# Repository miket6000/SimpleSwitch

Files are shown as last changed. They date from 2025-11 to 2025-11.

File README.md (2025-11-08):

# SimpleSwitch

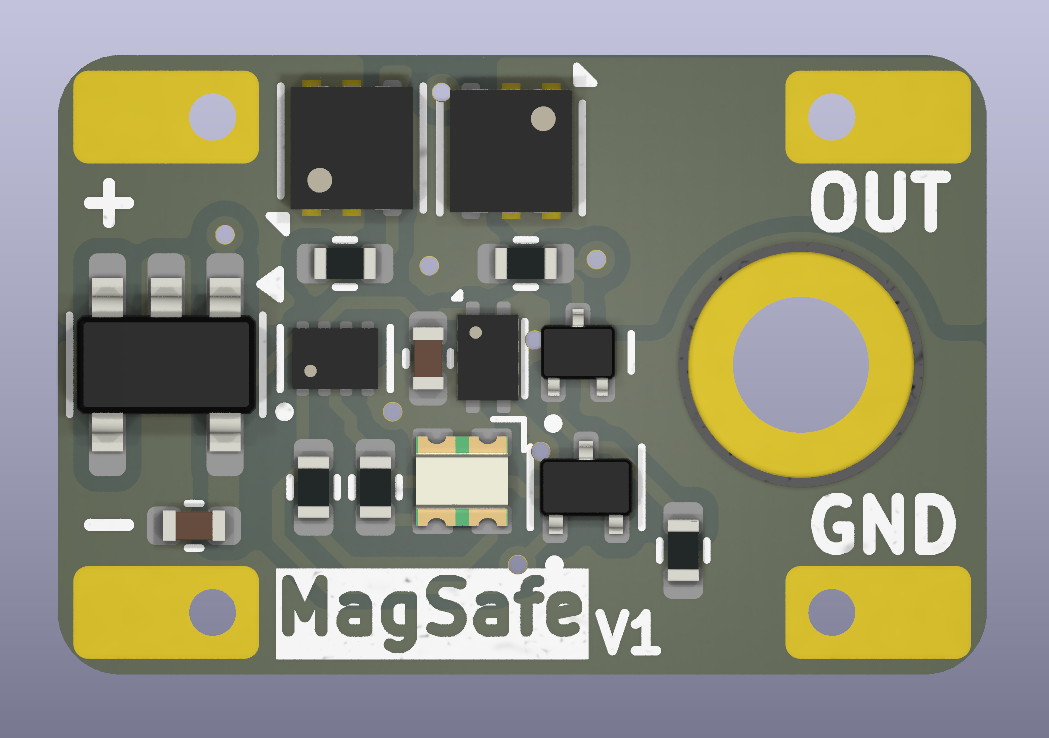
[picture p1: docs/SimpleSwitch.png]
Render of SimpleSwitch


SimpleSwitch is a magneticly operated electronic switch designed for model rocketry. It is a 15x10mm PCB with an input and output capable of switching approximately 4A continuous and 10A for 10s. It can accept an input voltage of up to 12V and also includes reverse polarity protection to prevent damage to the switch or downstream electronics in the event that the battery is accidentally connected backwards.

It is designed specifically to be easy to turn on, but to require multiple steps to turn off. This is to prevent issues with accidental turn off which can occur with traditional magnetic switches when they pass by magnatized hardware on launch towers/rails.

The magnetic switch draws a very small amount of power from the battery when plugged in. This is calculated at 3uA worst case, so a small 150mAh 1s battery should last approximately 5 years. On larger batteries this is quickly swamped by the batteries self discharge rate.

## Operation

Use of the SimpleSwitch is easy. Bringing a magnetic south pole near the top of the board will result in the switch turning on and illuminating both the red and green LEDs, the switch is now in the "ON" state. 

To turn off the switch you nead to put a North pole near the switch which will cause the red LED to turn off ("OK" state). Bringing a South pole near the switch will then cause the green LED to turn off and the red LED to turn back on ("WARNING" State). One more north pole will cause the red LED to turn off and the switch to disable the output ("OFF" State).

In summary as you alernate South-\>North-\>South-\>North you step through the states as shown below:

| Magnetic Pole | State Name  | Red LED | Green LED | Switch State |
|---|---|---|---|---|
| | OFF | OFF | OFF | OFF |
| SOUTH | ON | ON | ON | ON |
| NORTH | OK | OFF | ON | ON |
| SOUTH | WARNING | ON | OFF | ON |
| NORTH | OFF | OFF | OFF | OFF |

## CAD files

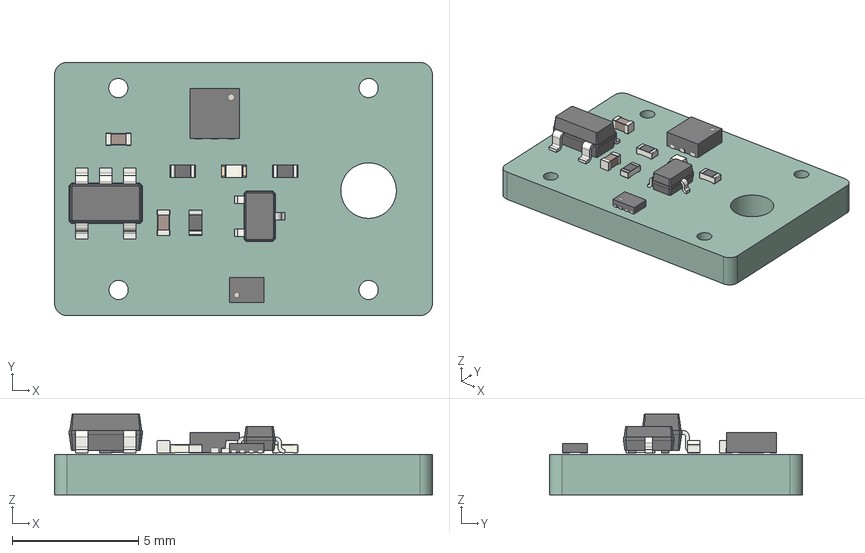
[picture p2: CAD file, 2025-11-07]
hardware/magnetic_switch.step
15.0 x 10.0 x 3.20 mm
R_0402_1005Metric x 3
WSON_6_1EP_2x2mm_P065mm_EP1x16mm
C_0402_1005Metric x 2
SOT_323_SC_70
X2SON_8_14x1mm_Pitch035mm
LED_0402_1005Metric
SOT_23_5
magnetic_switch_PCB

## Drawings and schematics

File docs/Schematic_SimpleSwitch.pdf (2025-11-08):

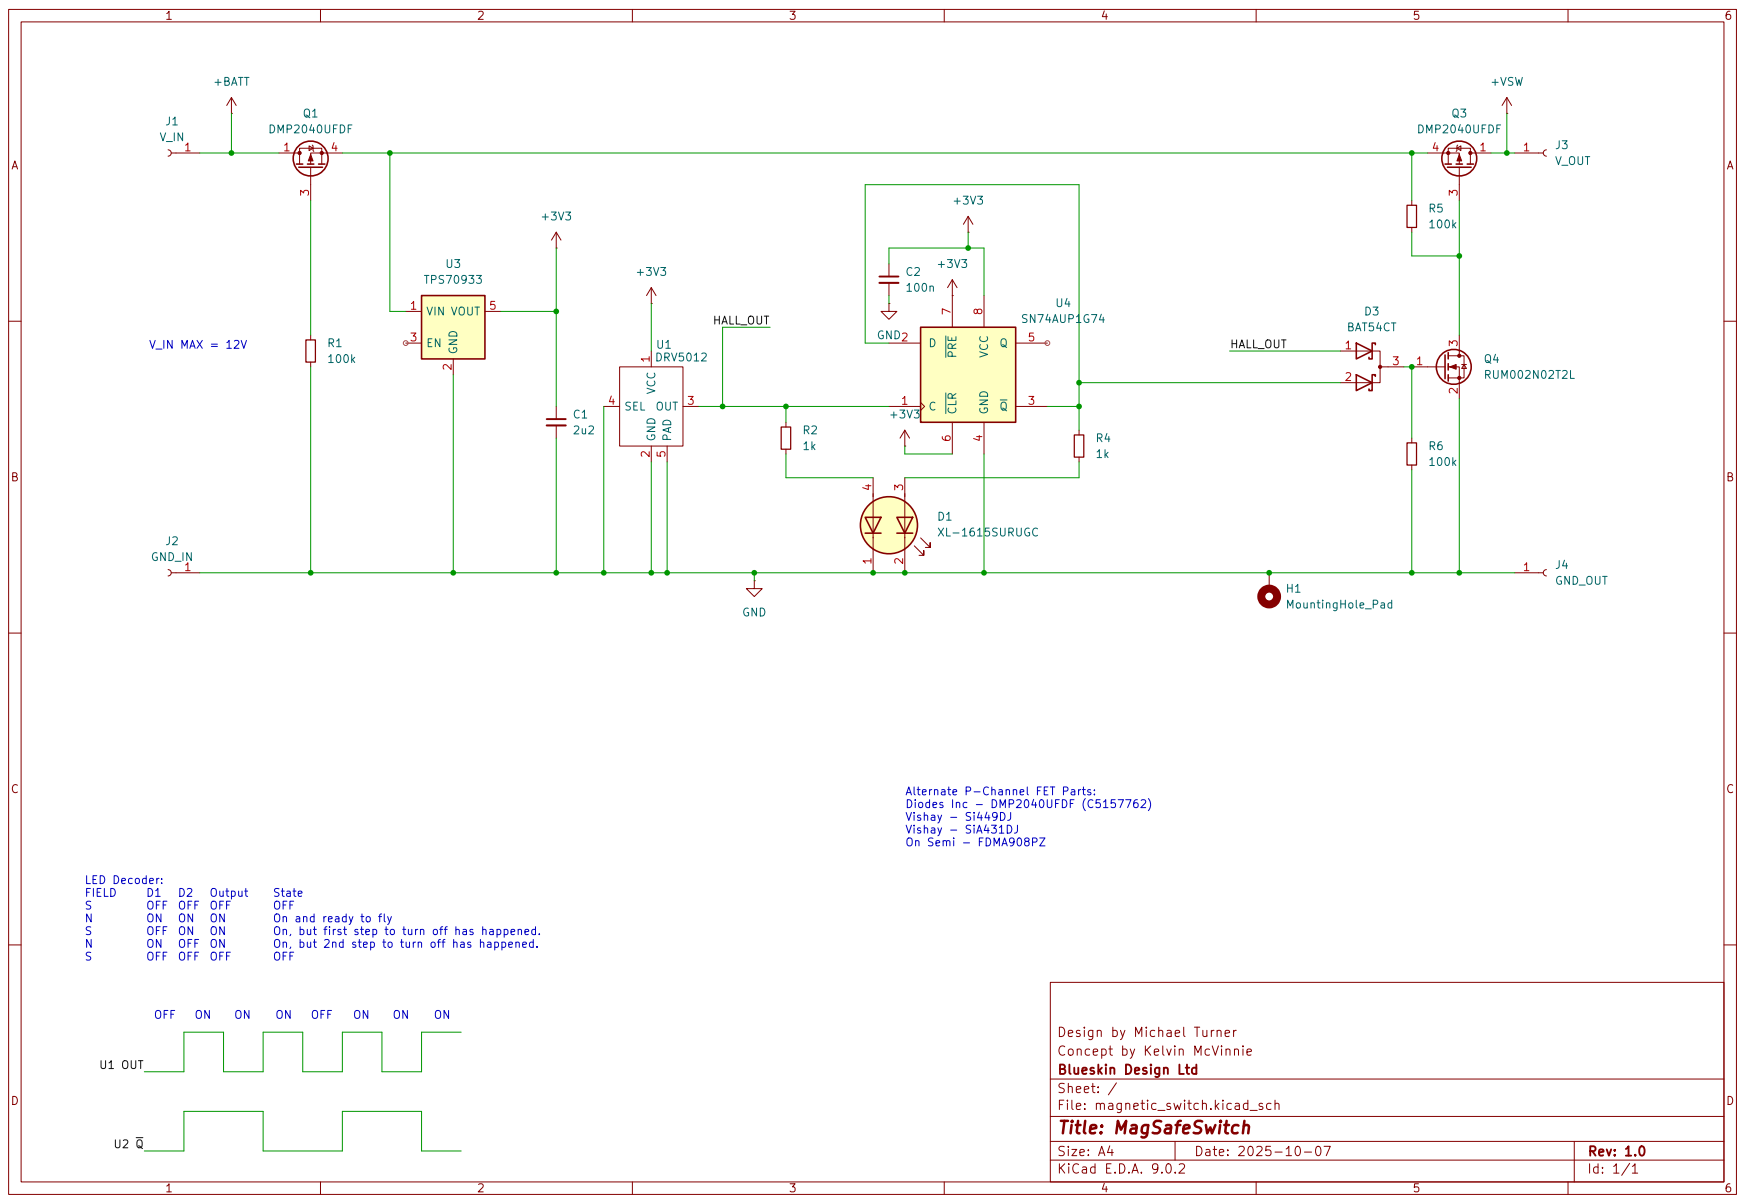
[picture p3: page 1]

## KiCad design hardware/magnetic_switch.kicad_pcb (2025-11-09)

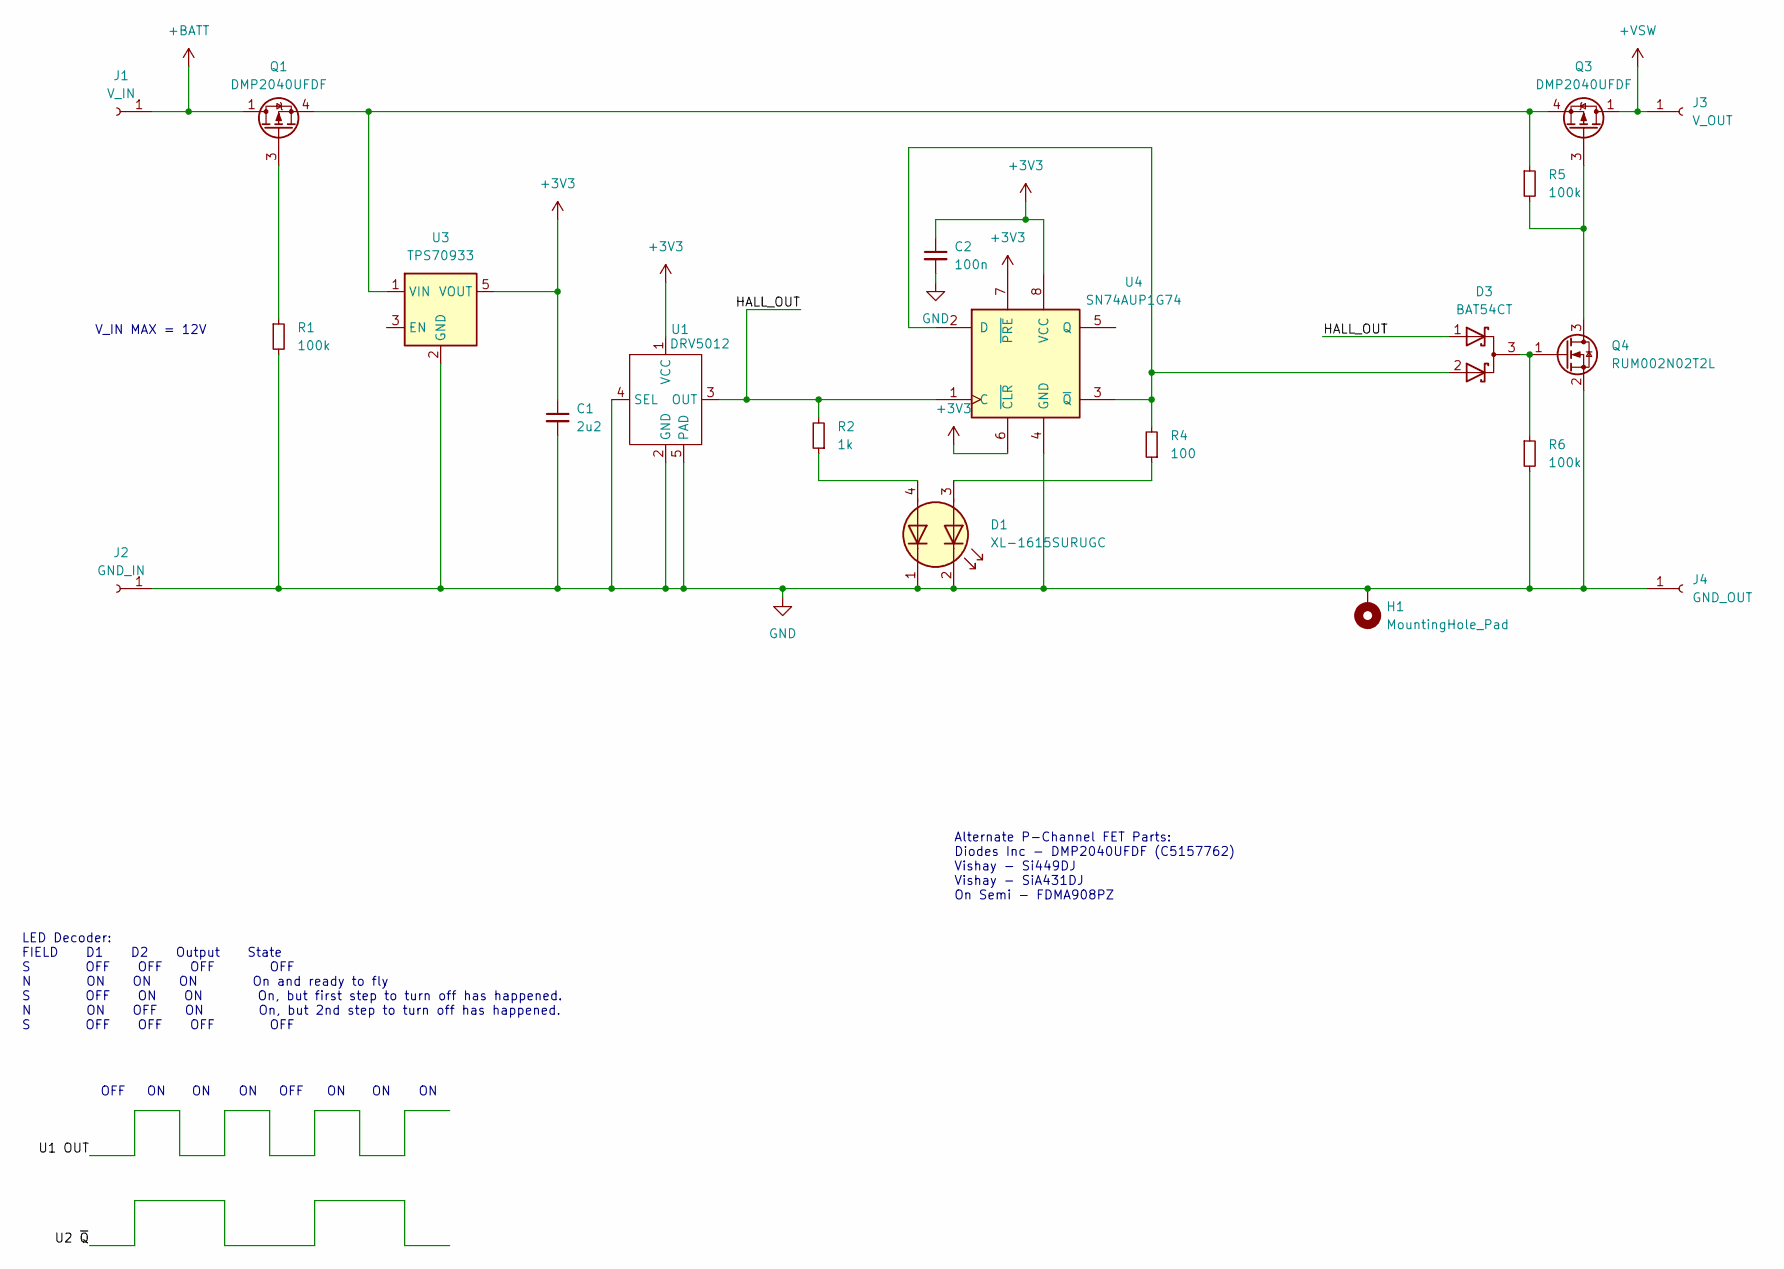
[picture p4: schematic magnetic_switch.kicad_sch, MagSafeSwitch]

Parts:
C1: 2u2; C_0402_1005Metric
C2: 100n; C_0402_1005Metric
D1: XL-1615SURUGC; LED_SMT_DUAL_1615; JLCPCB Part # C965839
D3: BAT54CT; SOT-523; JLCPCB Part # C134407
H1: MountingHole_Pad; MountingHole_2.2mm_M2_DIN965_Pad
J1: V_IN; WireSolderPad_w_hole
J2: GND_IN; WireSolderPad_w_hole
J3: V_OUT; WireSolderPad_w_hole
J4: GND_OUT; WireSolderPad_w_hole
Q1, Q3: DMP2040UFDF; Vishay_PowerPAK_SC70-6L_Single; JLCPCB Part # C5157762
Q4: RUM002N02T2L; SOT-723; JLCPCB Part # C250130
R1, R5, R6: 100k; R_0402_1005Metric
R2: 1k; R_0402_1005Metric
R4: 100; R_0402_1005Metric
U1: DRV5012; X2SON_4_EP; JLCPCB Part # C2655038
U3: TPS70933; SOT-23-5; JLCPCB Part # C89347
U4: SN74AUP1G74; X2SON-8_1.4x1mm_P0.35mm; JLCPCB Part # C2677745

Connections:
+3V3: C1.1, C2.1, U1.1 (VCC), U3.5 (VOUT), U4.6 (~CLR), U4.7 (~PRE), U4.8 (VCC)
+BATT: J1.1, Q1.1 (D)
+VSW: J3.1, Q3.1 (D)
/HALL_OUT: D3.1 (A), R2.2, U1.3 (OUT), U4.1 (C)
GND: C1.2, C2.2, D1.1 (K2), D1.2 (K1), H1.1, J2.1, J4.1, Q4.2 (S), R1.2, R6.2, U1.2 (GND), U1.4 (SEL), U1.5 (PAD), U3.2 (GND), U4.4 (GND)
unnamed: D1.3 (A1), R4.1
unnamed: D1.4 (A2), R2.1
unnamed: D3.3 (K), Q4.1 (G), R6.1
unnamed: Q1.3 (G), R1.1
unnamed: Q1.4 (S), Q3.4 (S), R5.1, U3.1 (VIN)
unnamed: Q3.3 (G), Q4.3 (D), R5.2
unnamed: D3.2 (A), R4.2, U4.2 (D), U4.3 (~Q)

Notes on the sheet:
OFF
LED Decoder: FIELD D1 D2 Output State S OFF OFF OFF OFF N ON ON ON On and ready to fly S OFF ON ON On, but first step to turn off has happened. N ON OFF ON On, but 2nd step to turn off has happened. S OFF OFF OFF OFF
V_IN MAX = 12V
Alternate P-Channel FET Parts: Diodes Inc - DMP2040UFDF (C5157762) Vishay - Si449DJ Vishay - SiA431DJ On Semi - FDMA908PZ

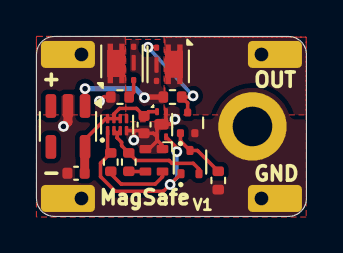
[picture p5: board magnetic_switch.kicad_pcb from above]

Board: 2 copper layers, 15.0 x 10.0 mm, 20 parts (0 on the bottom side), 12 nets.

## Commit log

2024-12-06 Minor cleanup of the schematic
    [magnetic_switch.kicad_sch]
2025-02-07 Corrected issue with regulator enable pin which needs to be left floating, NOT tied to VCC and updated README to reflect the fact that testing is complete.
    [magnetic_switch.kicad_pcb, magnetic_switch.kicad_sch]
2025-02-10 updated pdf schematic to match KiCAD schematic
2025-11-07 updated to smaller components and re-layed out.
    [magnetic_switch.kicad_pcb, magnetic_switch.kicad_sch, magnetic_switch.step]
2025-11-08 added a linear regulator to allow up to +12V input. This version was sent for manufacture.
    [magnetic_switch.kicad_pcb, magnetic_switch.kicad_sch]
2025-11-08 Updated state table to include magnetic poles
2025-11-08 Added discussion of input voltage to readme.
2025-11-09 added missing via on R1 gnd
    [magnetic_switch.kicad_pcb]
